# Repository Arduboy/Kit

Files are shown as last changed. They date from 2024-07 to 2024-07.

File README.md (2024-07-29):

# Arduboy Kit

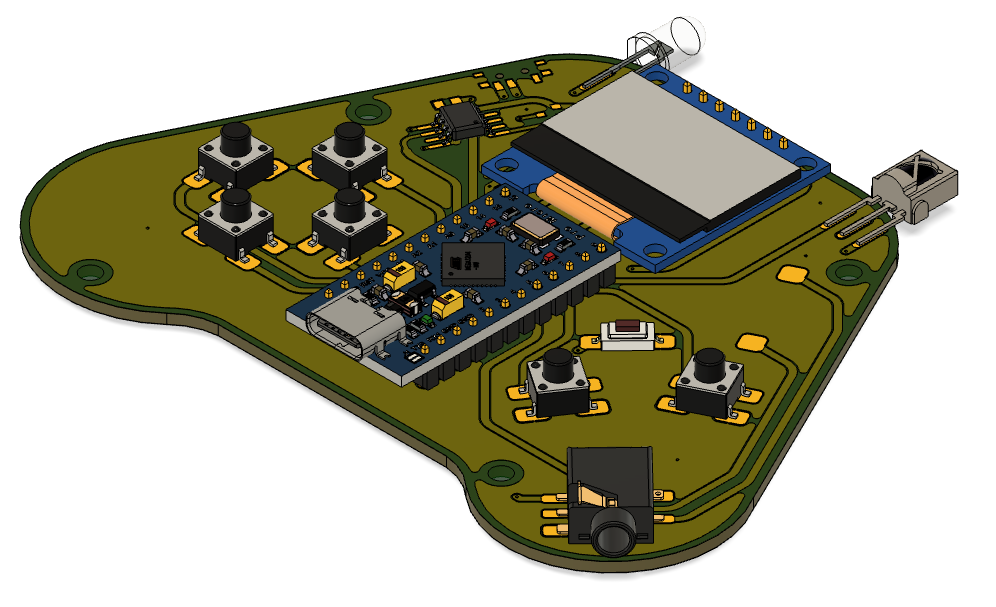
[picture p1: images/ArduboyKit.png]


This repository includes all of the files you need to build your own Arduboy Kit

## Important Notes

Arduboy Kit uses the "Alternate Wiring" pinout configuration. The pins necessary to match the production Arduboy FX are not available on the Pro-Micro module, and thus alternate assignments are made in software, at compile time using a custom board file. All code for the Arduboy Kit must be compiled for alternate wiring.

Solder jumpers are available on the back of the PCB, to switch to a standard wiring configuration, however this requires placing a PNP transistor along with a resistor. This modification is currently undocumented.

Additionally, Infrared LED has been placed instead of the Red led usually on Pin 9. An Infrared receiver has it's data pin instead of the Blue led usually on Pin 10.

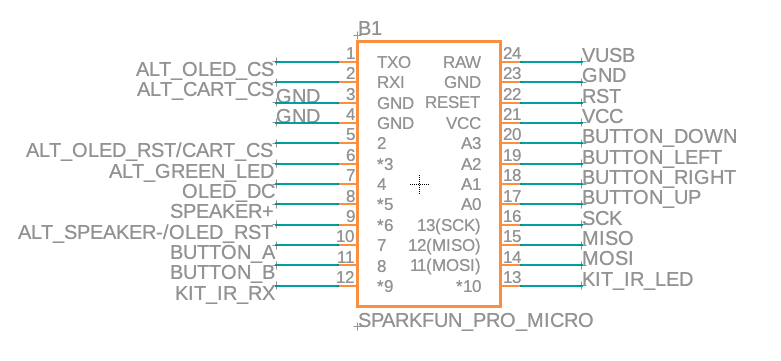
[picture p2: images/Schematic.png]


## Eagle and Gerber Board Files

Use your favorite PCB board manufacturer to produce your own circuit boards. Files are contained within the Board Files folder

## Bill of Materials

List of required materials along with URL links to source the components. The links are for reference only, and are not endorsements of any particular seller. Purchase at your own discretion.

## Instructions

For instructions how to assemble the board are available within this repo:
- <a href="https://arduboy.github.io/Kit/Instructions.html">Web Instructions</a>
- <a href="https://arduboy.github.io/Kit/Instructions.pdf">Print Instructions</a>

A web utility for flashing all of the games to the Kit is within this repo:
- <a href="./index.html">Arduboy Kit Web Flasher</a>

and hosted at:
- <a href="https://arduboy.github.io/Kit">arduboy.github.io/Kit</a>

## 3d Printables

The step file for the Arduboy Kit and an example bottom clamshell case are available within the 3d Files folder.

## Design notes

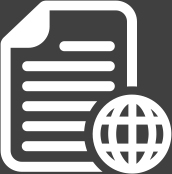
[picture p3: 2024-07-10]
images/webdoc.png

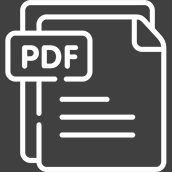
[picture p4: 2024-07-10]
images/pdfdoc.png

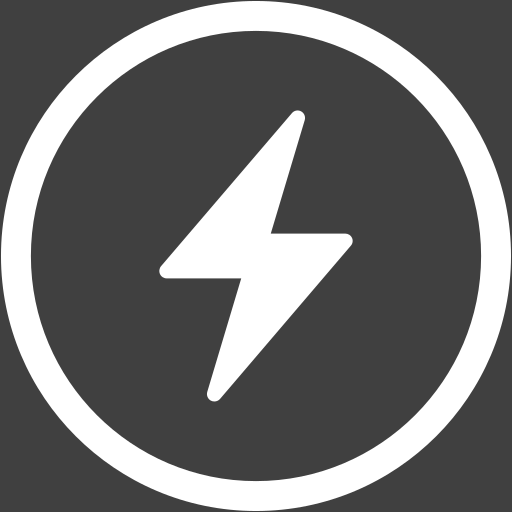
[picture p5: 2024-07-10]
images/buttons.png

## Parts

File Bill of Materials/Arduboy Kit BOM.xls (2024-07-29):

Parts | Qty | Device | Value | Package | Description | Amazon | Ebay | Aliexpress | Mouser | Digikey
B1 | 1 | Pro-Micro |  |  | Arduino Pro Micro or Compatible | https://www.amazon.com/Teyleten-Robot-Bootloadered-Development-Microcontroller/dp/B08THVMQ46 | https://www.ebay.com/itm/225896354066?itmmeta=01J4062VWNXTNZH98P5FTJPV9X | https://www.aliexpress.us/item/2251832622204427.html
J1 | 1 | OLED Display |  | 7 Pins | OLED Module: SSD1306 0.96" SPI (7 pins) | https://www.amazon.com/HiLetgo-Serial-128X64-Display-Color/dp/B01MQPQF24 | https://www.ebay.com/itm/324687856035?itmmeta=01J4063TRE6Z9N0FPC6ZSBZF67 | https://www.aliexpress.us/item/3256806446154538.html
U1 | 1 | Flash Chip | W25Q128 | SOIC-8 | W25Q128 128Mb (16MB) Serial Flash Memory |  |  | https://www.aliexpress.us/item/3256803266279265.html | https://www.mouser.com/ProductDetail/Winbond/W25Q128JVSIQ?qs=qSfuJ%252Bfl%2Fd6tLXvPR4fl9w%3D%3D | https://www.digikey.com/en/products/detail/winbond-electronics/W25Q128JVSIQ/5803943
SW1, SW2, SW3, SW4, SW5, SW6 | 6 | Buttons | EVQQ2 | 6x6mm | SMT 6mm switch, EVQQ2 series or Compatible | https://www.amazon.com/DaFuRui-250pcs-Tactile-Momentary-Assortment/dp/B07KGR7L9M | https://www.ebay.com/itm/192616700952?itmmeta=01J4064WFBYJTKJRS1KBZA2AM5 | https://www.aliexpress.us/item/3256805658758223.html | https://www.mouser.com/ProductDetail/Panasonic/EVQ-Q2B02W?qs=WwqriLBepZseHl%252BZXHkVRg%3D%3D | https://www.digikey.com/en/products/detail/panasonic-electronic-components/EVQ-Q2F03W/762887
S1 | 1 | Reset Button |  | 6x3.5mm | Momentary Switch (Pushbutton) - SPST | https://www.amazon.com/dp/B0BN5X5422?psc=1&ref=ppx_yo2ov_dt_b_product_details | https://www.ebay.com/itm/232334338854?itmmeta=01J4064WFB4M83M4Q50A8XCX1Q
SPK | 1 | Speaker | 1109 |  |  |  |  | https://www.aliexpress.us/item/3256805619021745.html | https://www.mouser.com/ProductDetail/Mallory-Sonalert/AST1109MLTRQ?qs=GpRChIzryBM5c7g4uet5pQ%3D%3D | https://www.digikey.com/en/products/detail/mallory-sonalert-products-inc/AST1109MLTRQ/1284367
J7 | 1 | Headphone Jack | SJ1-3515-SMT-TR |  |  |  |  | https://www.aliexpress.us/item/3256801439835774.html | https://www.mouser.com/ProductDetail/CUI-Devices/SJ1-3515-SMT-TR?qs=WyjlAZoYn50EWh4ieUNQvw%3D%3D | https://www.digikey.com/en/products/detail/cui-devices/SJ1-3515-SMT-TR/659917
S8 | 1 | Power Switch (Optional) |  | SPST | SPDT Switch | https://www.amazon.com/uxcell-Position-Locking-Switch-7x2x1mm/dp/B01N25FBWD | https://www.ebay.com/itm/362590978655?itmmeta=01J406A62XX38BW04T5CT5HVWC
Q1 | 1 | PNP transistor (Optional) |  | SOT23-3 | PNP transistor with built in base resistor
R1 | 1 | Resistor (Optional) |  | R0805 | RESISTOR, American symbol |  |  | https://www.aliexpress.us/item/3256805874707460.html
X1 | 1 | Short Pin Headers

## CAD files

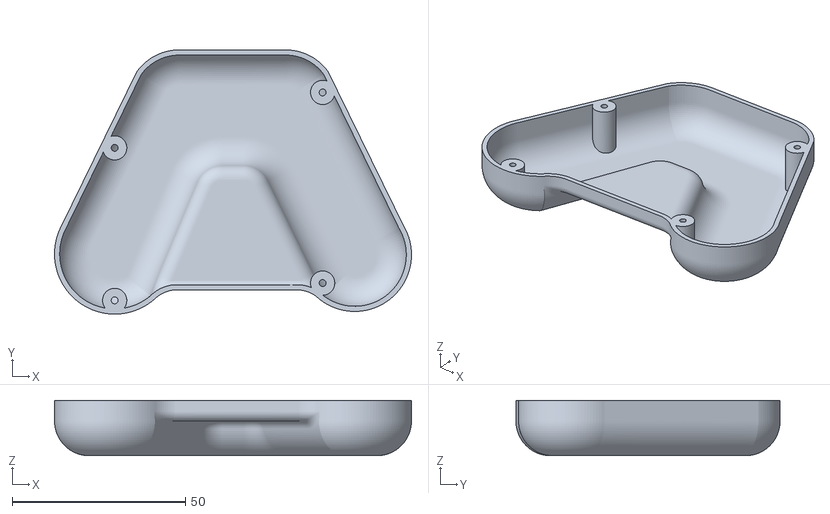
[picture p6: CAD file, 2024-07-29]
3d Files/Arduboy Kit Case.stl
103.0 x 76.2 x 16.0

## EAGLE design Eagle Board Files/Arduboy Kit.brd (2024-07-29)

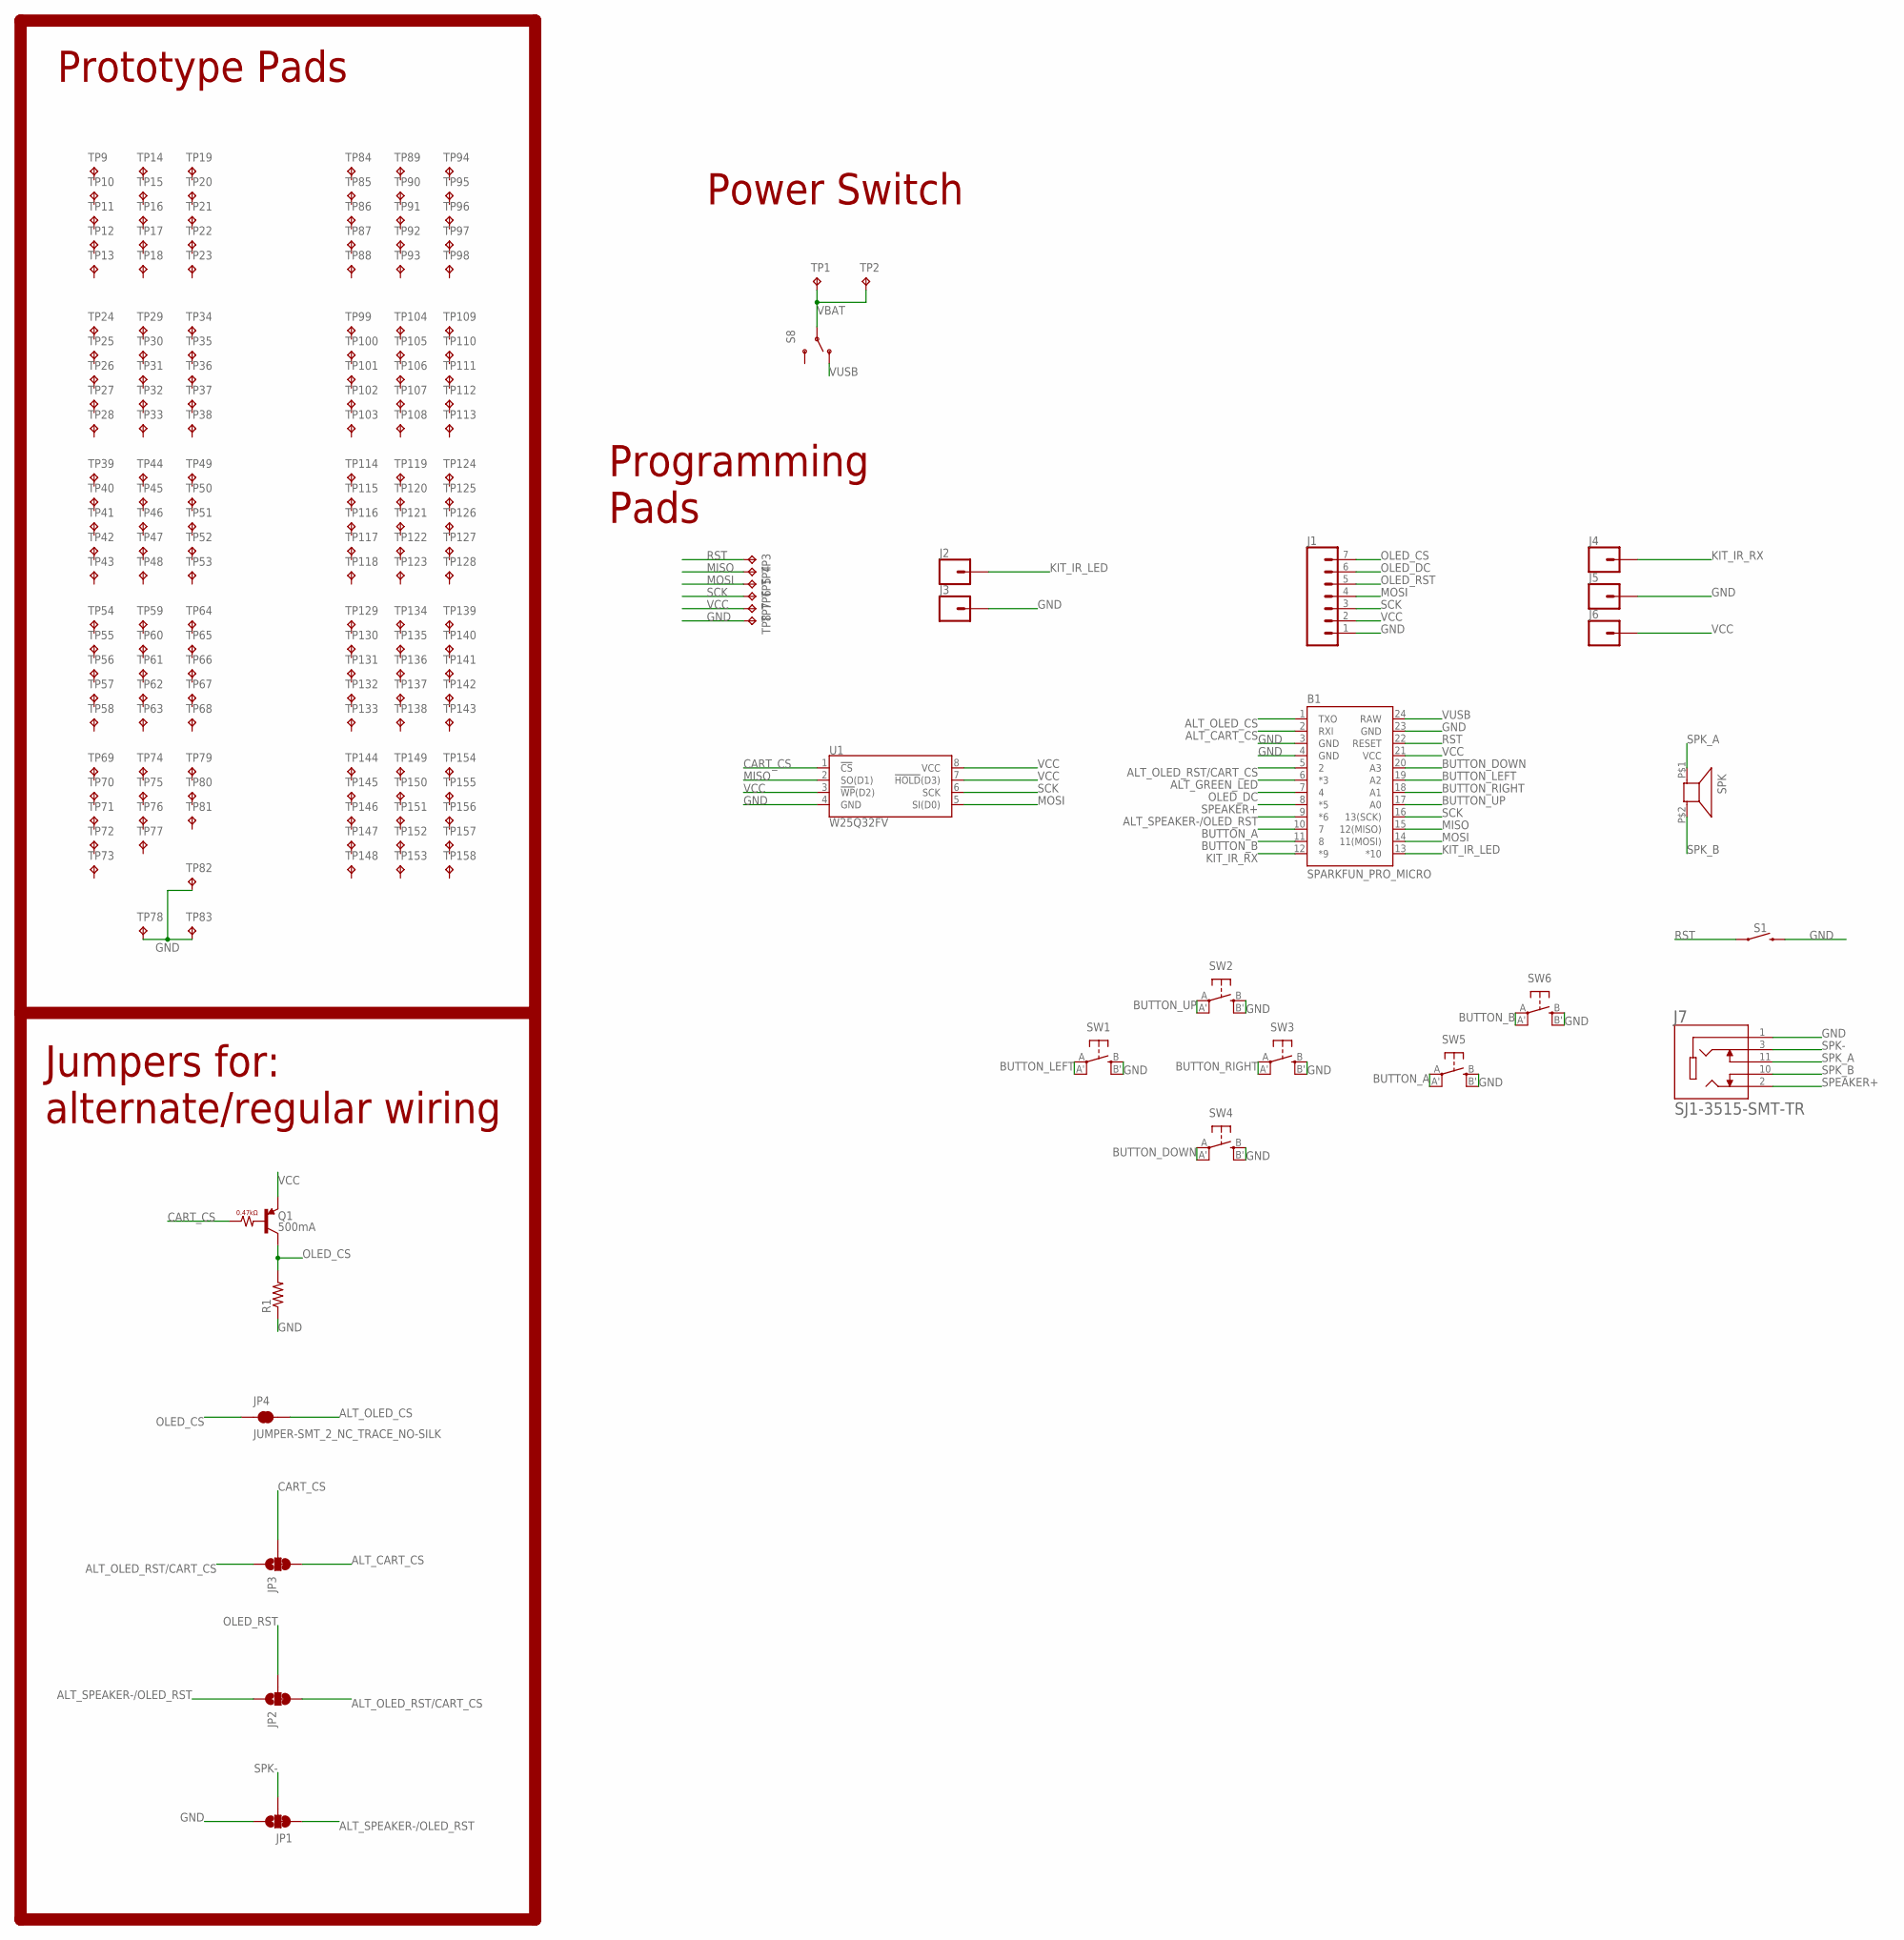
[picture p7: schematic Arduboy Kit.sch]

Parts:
B1: SPARKFUN_PRO_MICRO
J1: CONN_07NO_SILK; 1X07_NO_SILK
J2, J3, J4, J5, J6: CONN_01PAD; 1X01_SOLDER_PADS
J7: SJ1-3515-SMT-TR; CUI_SJ1-3515-SMT-TR
JP1, JP2, JP3: JUMPER-SMT_3_1-NC_TRACE_NO-SILK; SMT-JUMPER_3_1-NC_TRACE_NO-SILK
JP4: JUMPER-SMT_2_NC_TRACE_NO-SILK; SMT-JUMPER_2_NC_TRACE_NO-SILK
Q1: 500mA; SOT23-3
R1: R-US_R0805; R0805
S1: MOMENTARY-SWITCH-SPST-SMD-6.0X3.5MM; TACTILE_SWITCH_SMD_6.0X3.5MM
S8: SWITCH-SPDT-SMD-A; SWITCH-SPST-SMD-A
SPK: O_SPK_2_FLEX; O_SPK_FLEX
SW1, SW2, SW3, SW4, SW5, SW6: SPST_TACT-EVQQ2; EVQ-Q2
TP1, TP2, TP9, TP10, TP11, TP12, TP13, TP14, TP15, TP16, TP17, TP18, TP19, TP20, TP21, TP22, TP23, TP24, TP25, TP26, TP27, TP28, TP29, TP30, TP31, TP32, TP33, TP34, TP35, TP36, TP37, TP38, TP39, TP40, TP41, TP42, TP43, TP44, TP45, TP46, TP47, TP48, TP49, TP50, TP51, TP52, TP53, TP54, TP55, TP56, TP57, TP58, TP59, TP60, TP61, TP62, TP63, TP64, TP65, TP66, TP67, TP68, TP69, TP70, TP71, TP72, TP73, TP74, TP75, TP76, TP77, TP78, TP79, TP80, TP81, TP82, TP83, TP84, TP85, TP86, TP87, TP88, TP89, TP90, TP91, TP92, TP93, TP94, TP95, TP96, TP97, TP98, TP99, TP100, TP101, TP102, TP103, TP104, TP105, TP106, TP107, TP108, TP109, TP110, TP111, TP112, TP113, TP114, TP115, TP116, TP117, TP118, TP119, TP120, TP121, TP122, TP123, TP124, TP125, TP126, TP127, TP128, TP129, TP130, TP131, TP132, TP133, TP134, TP135, TP136, TP137, TP138, TP139, TP140, TP141, TP142, TP143, TP144, TP145, TP146, TP147, TP148, TP149, TP150, TP151, TP152, TP153, TP154, TP155, TP156, TP157, TP158: TPTP20SQ; TP20SQ
TP3, TP4, TP5, TP6, TP7, TP8: TPTP15SQ; TP15SQ
U1: W25Q32FV; SOIC-8

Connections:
ALT_CART_CS: B1.2 (RXI), JP3.3
ALT_GREEN_LED: B1.6 (*3)
ALT_OLED_CS: B1.1 (TXO), JP4.2
ALT_OLED_RST/CART_CS: B1.5 (2), JP2.3, JP3.1
ALT_SPEAKER-/OLED_RST: B1.9 (*6), JP1.3, JP2.1
BUTTON_A: B1.10 (7), SW5.A, SW5.A' (P1)
BUTTON_B: B1.11 (8), SW6.A, SW6.A' (P1)
BUTTON_DOWN: B1.20 (A3), SW4.A, SW4.A' (P1)
BUTTON_LEFT: B1.19 (A2), SW1.A, SW1.A' (P1)
BUTTON_RIGHT: B1.18 (A1), SW3.A, SW3.A' (P1)
BUTTON_UP: B1.17 (A0), SW2.A, SW2.A' (P1)
CART_CS: JP3.2, Q1.1 (B), U1.1 (!CS!)
GND: B1.3 (GND), B1.4 (GND), B1.23 (GND), J1.1, J3.1, J5.1, J7.1, JP1.1, R1.1, S1.2, SW1.B (S), SW1.B' (S1), SW2.B (S), SW2.B' (S1), SW3.B (S), SW3.B' (S1), SW4.B (S), SW4.B' (S1), SW5.B (S), SW5.B' (S1), SW6.B (S), SW6.B' (S1), TP8.TP, TP78.TP, TP82.TP, TP83.TP, U1.4 (GND)
KIT_IR_LED: B1.13 (*10), J2.1
KIT_IR_RX: B1.12 (*9), J4.1
MISO: B1.15 (12(MISO)), TP4.TP, U1.2 (SO(D1))
MOSI: B1.14 (11(MOSI)), J1.4, TP5.TP, U1.5 (SI(D0))
OLED_CS: J1.7, JP4.1, Q1.3 (C), R1.2
OLED_DC: B1.7 (4), J1.6
OLED_RST: J1.5, JP2.2
RST: B1.22 (RESET), S1.1, TP3.TP
SCK: B1.16 (13(SCK)), J1.3, TP6.TP, U1.6 (SCK)
SPEAKER+: B1.8 (*5), J7.2
SPK-: J7.3, JP1.2
SPK_A: J7.11, SPK.P$1 (1)
SPK_B: J7.10, SPK.P$2 (2)
VBAT: S8.2, TP1.TP, TP2.TP
VCC: B1.21 (VCC), J1.2, J6.1, Q1.2 (E), TP7.TP, U1.3 (!WP!(D2)), U1.7 (!HOLD!(D3)), U1.8 (VCC)
VUSB: B1.24 (RAW), S8.1 (O)

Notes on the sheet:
Jumpers for: alternate/regular wiring
Prototype Pads
Power Switch
Programming Pads

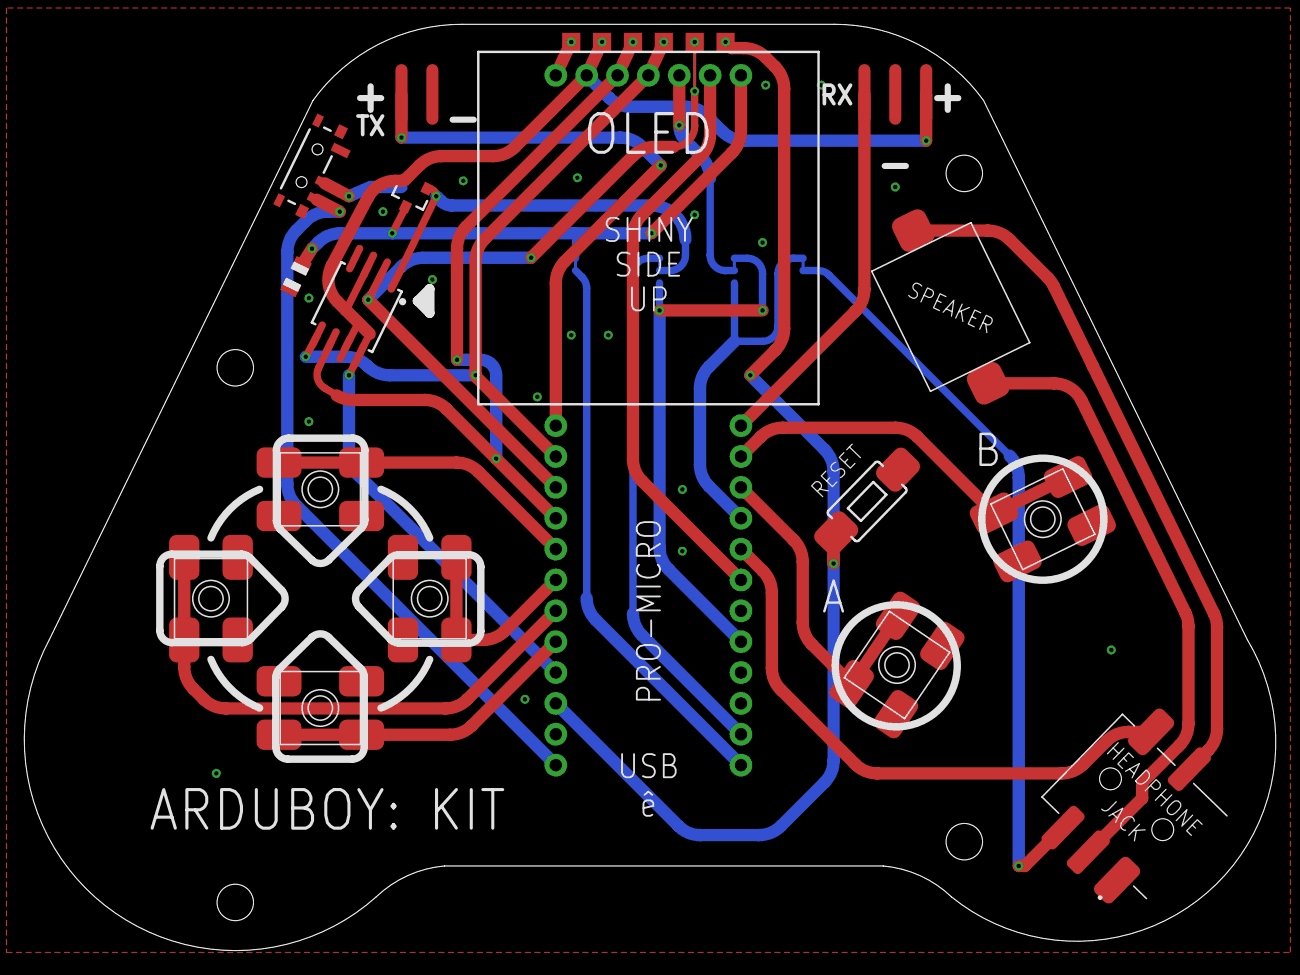
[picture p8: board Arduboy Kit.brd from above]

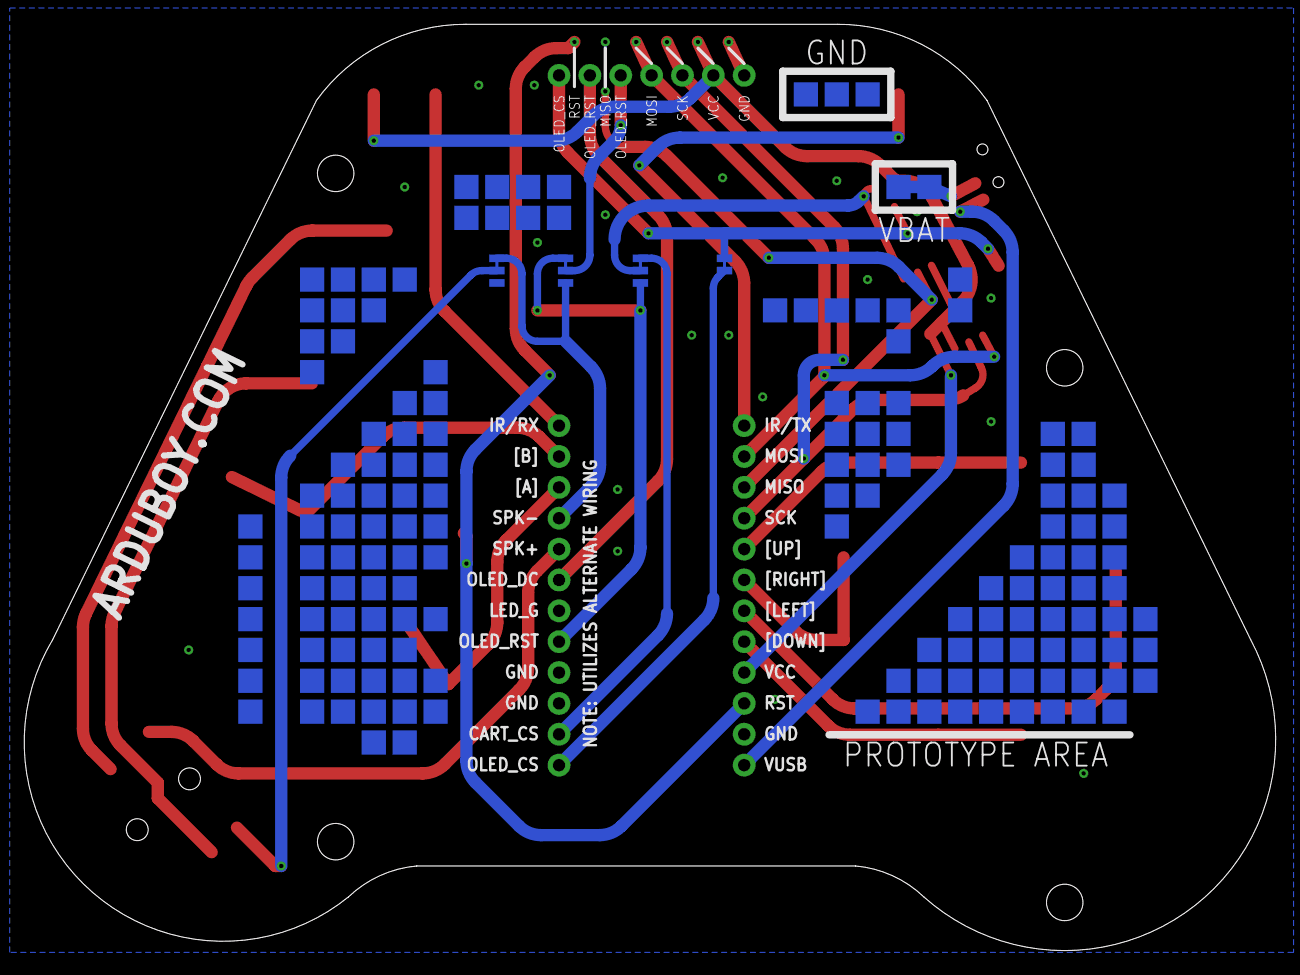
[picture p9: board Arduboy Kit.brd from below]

Board: 2 copper layers, 103.0 x 76.2 mm, 182 parts (156 on the bottom side), 28 nets.

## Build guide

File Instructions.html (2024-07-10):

Arduboy Kit

The Arduboy Kit is a video game system on a circuit board. Based on the popular Arduboy open-source game platform, it is designed to be assembled by hand.

Goals

The Goal of the Arduboy Kit is to be a casual and friendly introduction to surface mount soldering. Most introduction soldering kits feature only through-hole components. Surface mount kits can often be daunting. This kit aims to be somewhere in the middle. While many of the components are surface mount, they are large and easy to manipulate by hand.

Intermediate Difficulty

This kit will be best enjoyed by those with some soldering experience but is accessible to beginners with no experience at all. The most difficult component is the flash chip (SOP-8), but with a little bit of flux and determination anyone can successfully complete this kit. Ages 12 and up.

Materials

Required: Soldering Iron, Solder, Snips

Recommended: Flux, Solder Braid

Included: PCB, Pro-Micro, OLED Display, Short Pin-Headers, Reset Button, Buttons (x6),

Speaker, Headphone Jack, Flash Chip, Tweezers, Practice PCB, USB-C 2.0 Cable

Learn to Solder

Soldering involves melting a metal alloy to create a bond between components. Temperature control is important but almost just as important is our friend flux. Flux, or sometimes called rosin, is often integrated into the solder, cleans the surfaces, prevents oxidation, and enhances the soldering process by aiding the flow and bonding of the solder.

Begin by pre-heating the components and PCB. Apply solder where the components meet, heating the joint sufficiently to allow the solder to flow into place. Use as little solder as possible to avoid bridging nearby connections. Timing is key—hold the iron just long enough for proper wicking without burning the flux. Always ensure you are working in a well-ventilated area, clean the iron's tip frequently, and wear safety glasses to protect against splashes of hot solder.

Solder Practice

Contained within the Arduboy Kit is a green circuit board. Use this board to tune the settings of your iron and practice your soldering before getting started. Practice making solder connections and get a feeling for how quickly the solder melts and how it flows to the PCB. Try to use as little solder as possible. Experiment with and without pre-heating the pad, intentionally use too much solder, make a mess and of course – have fun!

Step 1: Header Pins to Modules

1.a  Cut and place short pin headers WARNING: Do not solder yet! | 1.b A blue and white drawing of a circuit board Description automatically generated Place Pro-Micro

It’s recommended to use the PCB for reference instead of counting the number of required pins. The PCB is used as a jig to align the pins to the module

CAUTION: When cutting pin headers, they can go flying

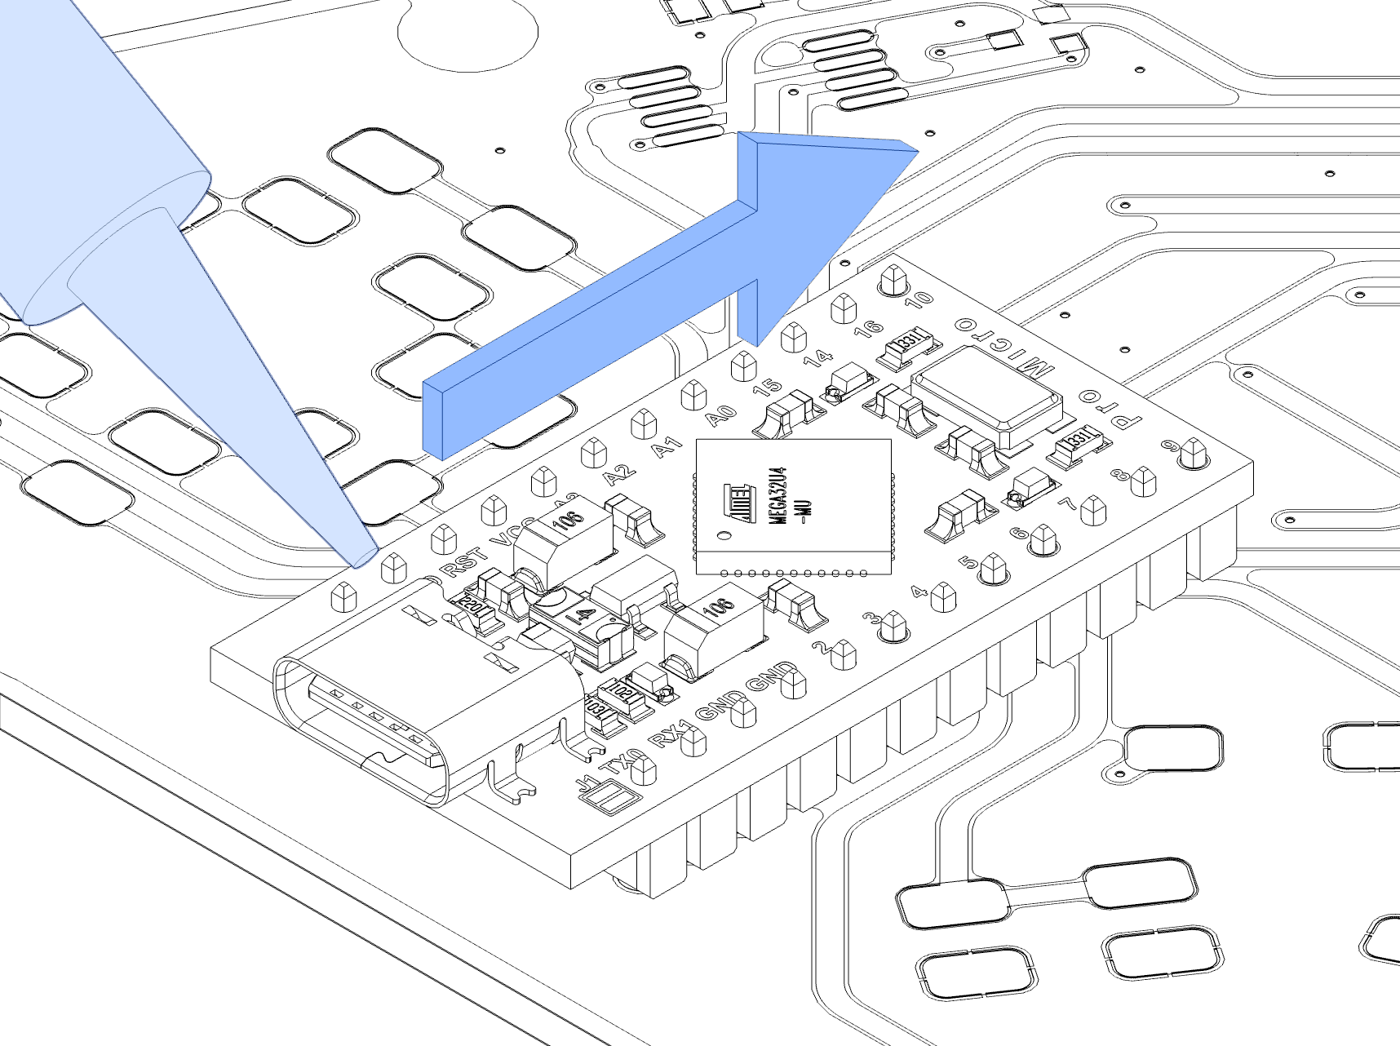
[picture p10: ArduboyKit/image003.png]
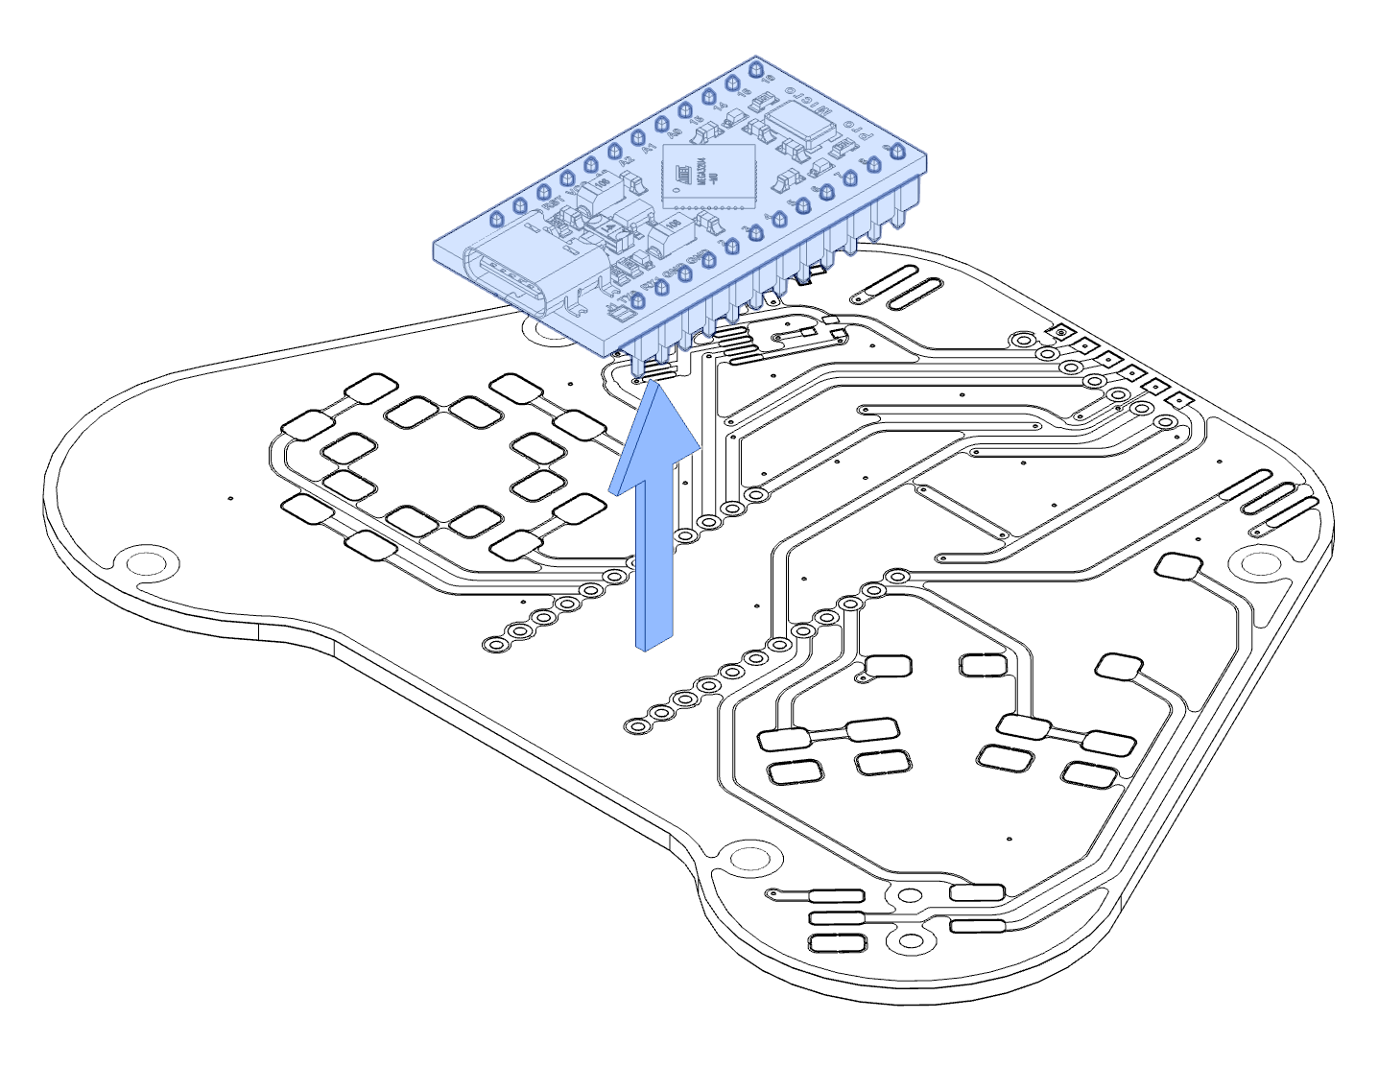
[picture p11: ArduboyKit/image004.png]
A diagram of a circuit board Description automatically generated
1.c  Solder pins to Pro-Micro | 1.d  Remove Pro-Micro with pins

CAUTION: Do not disturb components already mounted to the Pro-Micro. Hold the soldering iron in a way that safely clears other components

1.e  Cut and place pin headers WARNING: Do not solder yet! | 1.f A drawing of a computer chip Description automatically generated Place OLED Display Screen facing up

REMINDER: Do not solder to PCB yet, only solder pins to module

1.g A drawing of a device Description automatically generated Soler pins to OLED Display | 1.h A blue and white drawing of a circuit board Description automatically generated Remove OLED Display with pins

Step 2: Reset Button

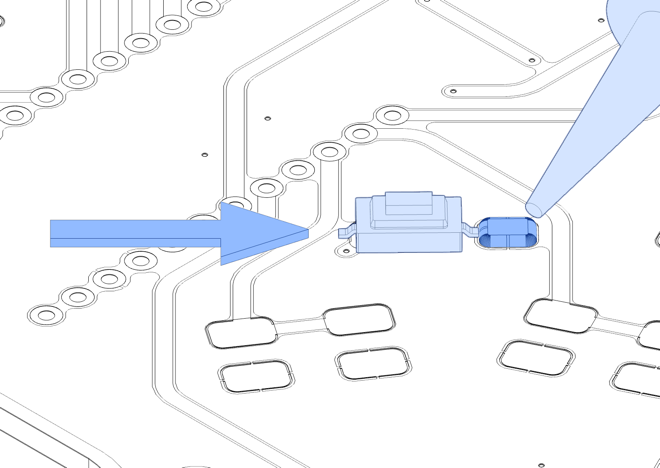
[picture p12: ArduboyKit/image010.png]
A blue arrow pointing to a blue object Description automatically generated with medium confidence
2.a A blue tube on a circuit board Description automatically generated Apply solder to one pad for the reset button NOTE: Only solder one pad | 2.b  While re-flowing solder, slide reset button into place, then remove iron.

This method of applying solder to the pad is known as “tinning”

2.c A blue and white drawing of a circuit board Description automatically generated Solder opposite lead of reset button to PCB | 2.d A blue drawing of a computer chip Description automatically generated Test the button! CAUTON: Wait for solder to cool

If you end up with solder tails, peaks generated when removing the soldering iron, try to complete the joint quicker as this is a sign of inadequate flux. This can be fixed by applying additional flux and re-flowing the solder joint.

Step 3: Buttons (x6)

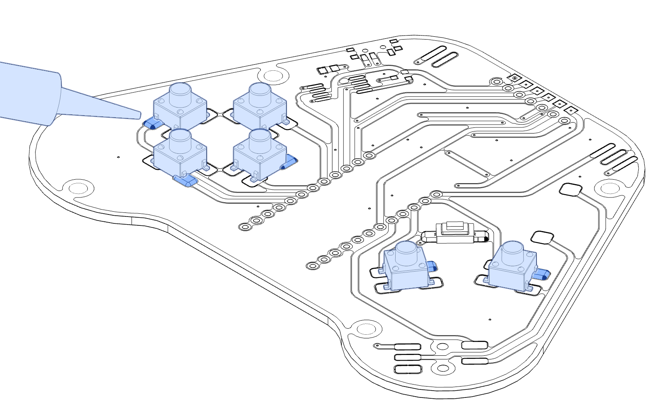
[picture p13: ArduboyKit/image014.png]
3.a A drawing of a circuit board Description automatically generated Apply solder to one pad for each of the 6 buttons NOTE: Only solder one pad each | 3.b  Place each of the 6 buttons, using the same re-flow sliding method as the reset button

3.c A drawing of a circuit board Description automatically generated Solder remaining 3 leads of each of the 6 buttons | 3.d A blue and white drawing of a circuit board Description automatically generated Test all the buttons! CAUTON: Wait for solder to cool

Step 4: Speaker

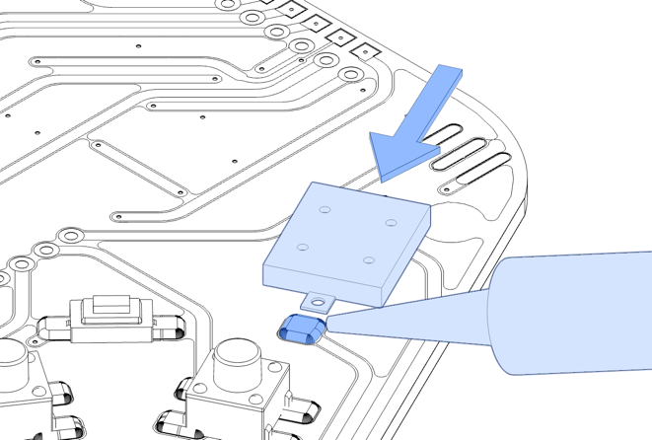
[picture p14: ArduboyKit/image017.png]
4.a  Solder one pad for the speaker and slide it into position while re-flowing | 4.b A blue and white drawing of a machine Description automatically generated Solder the opposite lead of the speaker

Step 5: Headphone Jack

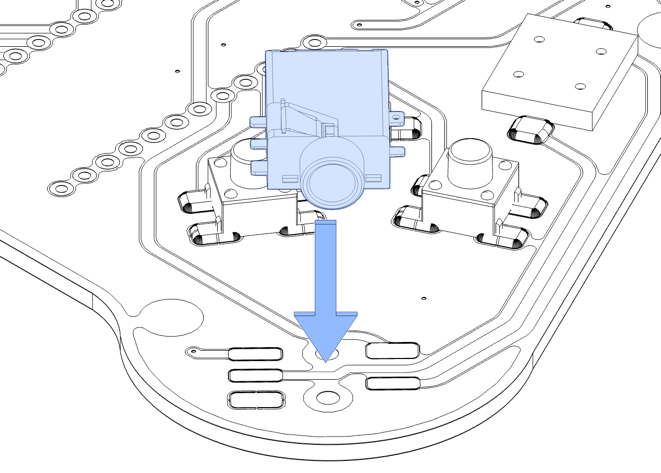
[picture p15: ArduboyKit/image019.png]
A blue arrow pointing at a camera Description automatically generated
5.a  Place headphone jack | 5.b A drawing of a machine Description automatically generated Solder leads of headphone jack

Tinning the pads are not necessary for the headphone jack as it has pins that locate it to the PCB

Step 6: Flash Chip

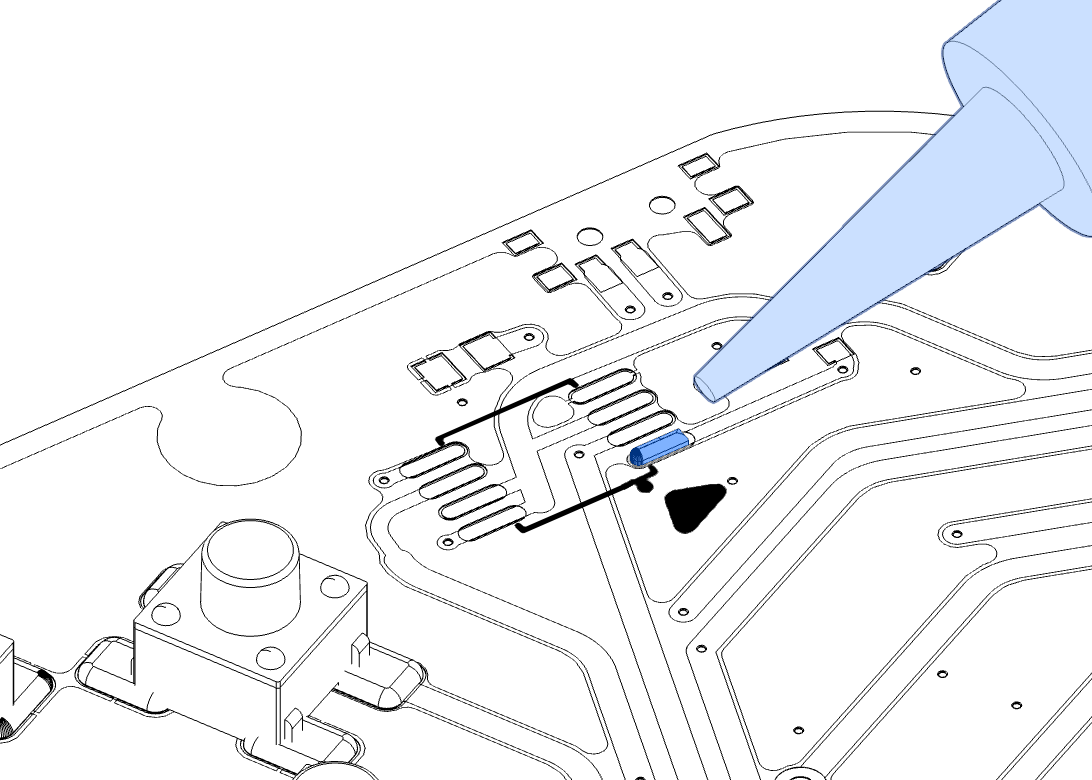
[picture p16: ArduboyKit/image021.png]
6.a  Solder the pad for the flash chip, closest to the circle and triangle marking on the PCB NOTE: This is pin 1 of the flash chip | 6.b A blue and white drawing of a computer chip Description automatically generated Align the marking on the flash chip with the marking on the PCB, slide into position while re-flowing solder pad

CRITICAL: Ensure the alignment of pin 1

6.c A blueprint of a computer chip Description automatically generated Solder the remaining leads of the flash chip TIP: Use small amount of solder | 6.d A blue and white drawing of a computer chip Description automatically generated If a solder bridge forms (connecting neighboring leads) it can easily be fixed in the next step

6.e A drawing of a circuit board Description automatically generated Apply small amount of flux to flash chip leads | 6.f A drawing of a computer chip Description automatically generated Use a dragging motion to swipe the soldering iron along the flash chip leads

Step 7: IR LED and Receiver

7.a A drawing of a circuit board Description automatically generated Solder one pad of each of the IR components | 7.b A blueprint of a computer chip Description automatically generated Cut IR LED and Receiver leads to length

CAUTION: Cutting the leads often causes them to go flying

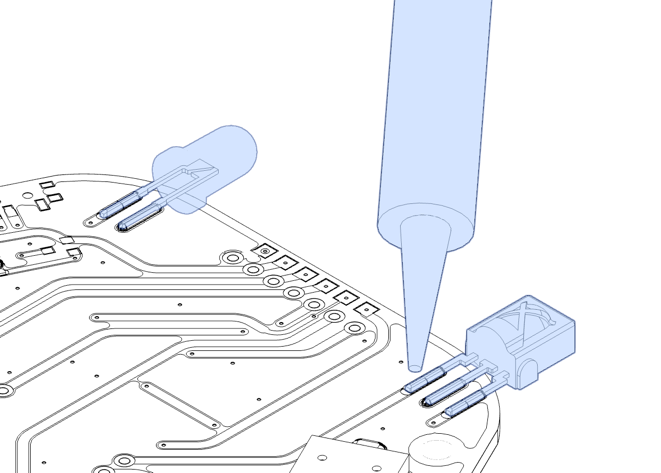
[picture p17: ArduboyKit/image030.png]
7.c  Orient the IR LED Polarity NOTE: Cathode (-) is the flat side of the lens | 7.d  Solder IR components to PCB using previous methods

Step 8: Modules to PCB

8.a  Place Pro-Micro and OLED Display with pins on PCB | 8.b  Flip PCB and solder pins to PCB NOTE: Ensure modules are flush with PCB

Step 9: Loading Games

Plug into PC via USB | Visit using chrome browser: https://arduboy.github.io/Kit | Use the one-click interface to upload all the games

Step 10: Making Games

Install Arduino software: https://www.arduino.cc/en/software

Add custom board files: https://boards.arduboy.com/homemade.json

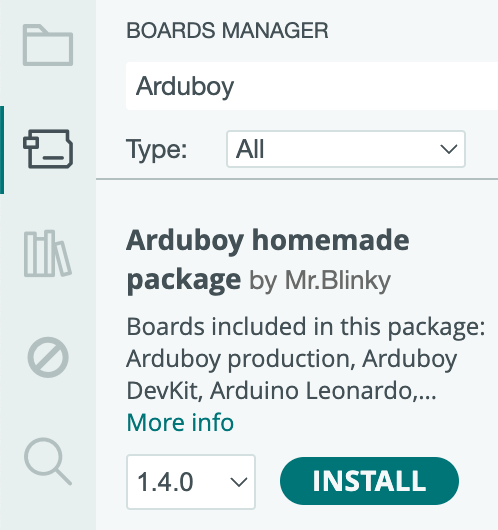
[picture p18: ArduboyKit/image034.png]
 | 

Configure board: Select from the tool’s menu the following configuration

 | Upload Hello Word Select from the menu: File > Examples > Arduboy2 > HelloWorld Select the Arduboy Kit on the active port: Tools > Port Upload the sketch using the Upload Button or: Sketch > Upload

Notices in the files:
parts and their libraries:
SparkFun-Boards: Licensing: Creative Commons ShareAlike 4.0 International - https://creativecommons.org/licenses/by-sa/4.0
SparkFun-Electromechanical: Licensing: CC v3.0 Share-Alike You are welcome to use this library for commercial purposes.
